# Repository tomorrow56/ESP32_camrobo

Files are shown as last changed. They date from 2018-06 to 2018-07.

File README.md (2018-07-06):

# ESP32_camrobo

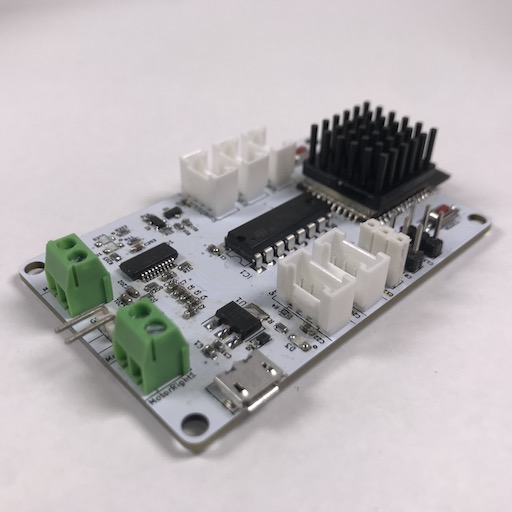
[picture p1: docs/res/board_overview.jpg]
ESP32Camrobo board


## Overview

[タミヤのカムプログラムロボット工作セット](http://www.tamiya.com/japan/products/70227/index.html) をマイコンロボット化するためのボート **ESP32Camrobo** と、それを使用した作例 **CrappyPark** についてのプロジェクトです。

## Get Started

### Arduinoでプログラミングするための準備

Arduinoでプログラムをボードに書き込むために以下の環境設定を行う。  

#### ESP32 ボードライブラリ

ESP32のBLE機能を使用するので、ESP32のボードライブラリを追加する。  

[arduino-esp32](https://github.com/espressif/arduino-esp32)  
**Installation Instructions** を参照してインストールする。  

参考) [Arduino IDEでESP32 BLEライブラリを導入](https://qiita.com/tomorrow56/items/afa06e206eec9fafcc7a)

#### ライブラリ

Arduino の **ライブラリマネージャ** から以下のライブラリをインストールする。  

- [Adafruit_NeoPixel](https://github.com/adafruit/Adafruit_NeoPixel)

## カムプログラムロボットの改造

ESP32Camroboをカムプログラムロボットに搭載し、改造する方法について解説しています。  

- [カムロボットの工作](./docs/make_robot/README.md)

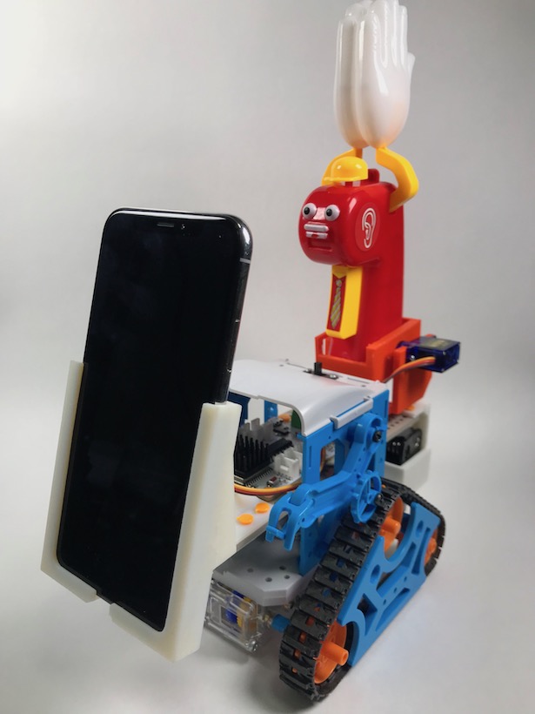
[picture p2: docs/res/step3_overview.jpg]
Camrobo Step3
  

*作成例(Step3)*

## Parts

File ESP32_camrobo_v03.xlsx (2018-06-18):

Reference | Value | Footprint | Note | Maker | URL
C1 | 10uF | Capacitors_SMD:C_0603
C2 | 10uF | Capacitors_SMD:C_0603
C3 | 10uF | Capacitors_SMD:C_0603
C4 | 10uF | Capacitors_SMD:C_0603
C5 | 10uF | Capacitors_SMD:C_0603
C6 | 10uF | Capacitors_SMD:C_0603
C7 | 10uF | Capacitors_SMD:C_0603
C8 | 10uF | Capacitors_SMD:C_0603
C9 | 10uF | Capacitors_SMD:C_0603
C10 | 0.1u | Capacitors_SMD:C_0603
C11 | 0.1u | Capacitors_SMD:C_0603
C12 | 10uF | Capacitors_SMD:C_0603
C13 | 10uF | Capacitors_SMD:C_0603
C14 | 10uF | Capacitors_SMD:C_0603
C15 | 10uF | Capacitors_SMD:C_0603
C16 | 10uF | Capacitors_SMD:C_0603
C17 | 10uF | Capacitors_SMD:C_0603
C20 | 10uF | Capacitors_SMD:C_0603
C22 | 10uF | Capacitors_SMD:C_0603
C200 | 10u | Capacitors_SMD:C_0603
C201 | 47p | Capacitors_SMD:C_0603
C202 | 47p | Capacitors_SMD:C_0603
C203 | 0.1u | Capacitors_SMD:C_0603
D1 | 1N4148 | Diodes_SMD:D_SOD-323
D2 | 1N4148 | Diodes_SMD:D_SOD-323
D3 | PowerLED | LEDs:LED_0805
D200 | RxLED | LEDs:LED_0805
D201 | TxLED | LEDs:LED_0805
Q1 | S8050 | TO_SOT_Packages_SMD:SOT-23
Q2 | S8050 | TO_SOT_Packages_SMD:SOT-23
R1 | 1k | Resistors_SMD:R_0603
R2 | 270 | Resistors_SMD:R_0603
R4 | 10k | Resistors_SMD:R_0603
R5 | 10k | Resistors_SMD:R_0603
R10 | 1k | Resistors_SMD:R_0603
R11 | 1k | Resistors_SMD:R_0603
R12 | 10k | Resistors_SMD:R_0603
R14 | 10k | Resistors_SMD:R_0603
R15 | 10k | Resistors_SMD:R_0603
R16 | 10k | Resistors_SMD:R_0603
R18 | 270 | Resistors_SMD:R_0603
R19 | DNP | footprint:SOLDERJUMPER_REFLOW
R21 | 270 | Resistors_SMD:R_0603
R200 | 27 | Resistors_SMD:R_0603
R201 | 27 | Resistors_SMD:R_0603
R202 | 1k | Resistors_SMD:R_0603
R203 | 1k | Resistors_SMD:R_0603
U1 | ADP3338AKCZ-3.3-RL | TO_SOT_Packages_SMD:SOT-223-3_TabPin2
U201 | FT231XS | SMD_Packages:SSOP-20
U301 | ESP-WROOM-32 | footprint:ESP-WROOM-32_aki
MicroUSB1 | USB_OTG | Connectors:USB_Micro-B
MODE1 | MODE | Buttons_Switches_SMD:SW_SPST_FSMSM
RESET1 | RESET | Buttons_Switches_SMD:SW_SPST_FSMSM
IC1 | L293D | Housings_DIP:DIP-16_W7.62mm_LongPads | IC MOTOR DRIVER PAR 16-DIP | STMicroelectronics
GroveANA1 | CONN_01X04 | footprint:Grove 2x2.00mm_Straight
GroveDIGI0 | CONN_01X04 | footprint:Grove 2x2.00mm_Straight
GroveDIGI1 | CONN_01X04 | footprint:Grove 2x2.00mm_Straight
GroveI2C1 | CONN_01X04 | footprint:Grove 2x2.00mm_Straight
GroveUART1 | CONN_01X04 | footprint:Grove 2x2.00mm_Straight
Neopixel1 | CONN_01X03 | Pin_Headers:Pin_Header_Straight_1x03_Pitch2.54mm
Servo1 | CONN_01X03 | Pin_Headers:Pin_Header_Straight_1x03_Pitch2.54mm
Servo2 | CONN_01X03 | Pin_Headers:Pin_Header_Straight_1x03_Pitch2.54mm
MotorPower1 | Terminal_01X02_FEMALE | Pin_Headers:Pin_Header_Angled_1x02_Pitch2.54mm
MotorLeft1 | Terminal_01X02_FEMALE | footprint:Terminal_2pin_Pitch3.5mm
MotorRight1 | Terminal_01X02_FEMALE | footprint:Terminal_2pin_Pitch3.5mm

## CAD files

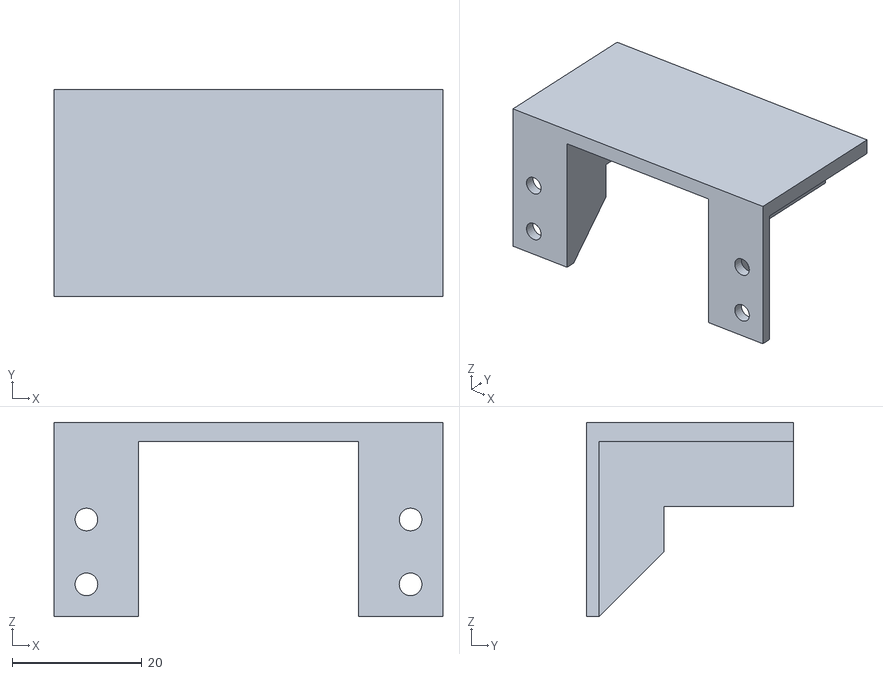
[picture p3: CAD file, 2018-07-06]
3d_parts/phone-base.stl
60.0 x 32.0 x 30.0

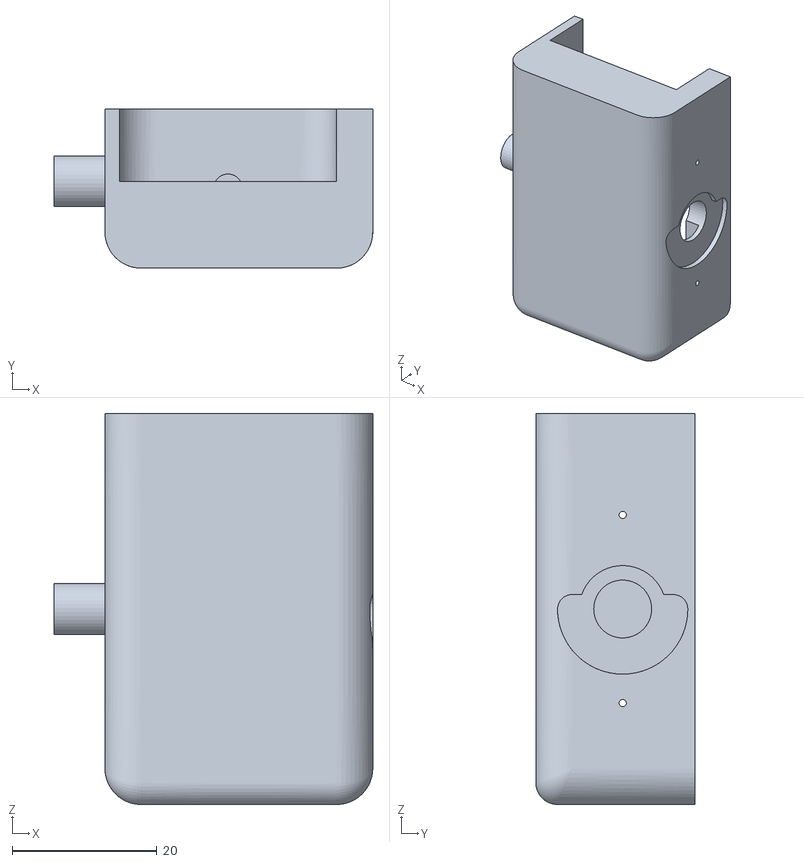
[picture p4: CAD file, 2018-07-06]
3d_parts/cp-mount-a.stl
44.0 x 22.0 x 54.0

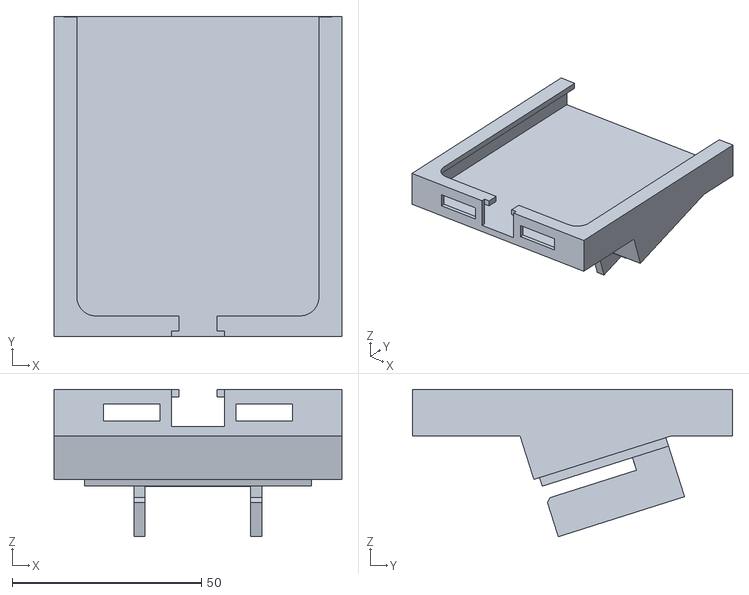
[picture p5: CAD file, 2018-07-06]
3d_parts/phone-mount-iphone-x-2017.stl
76.0 x 84.5 x 38.9

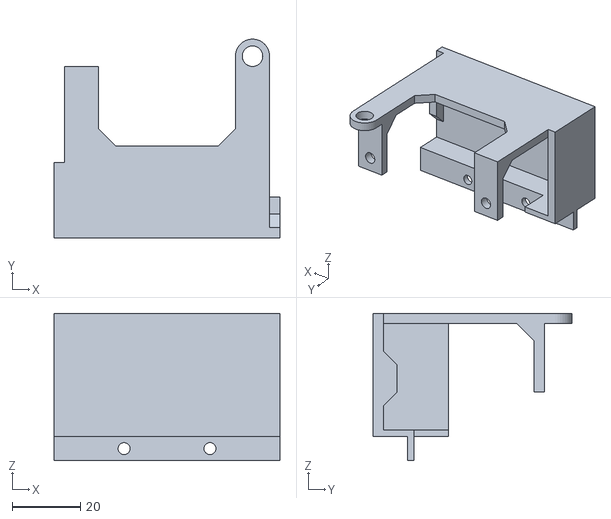
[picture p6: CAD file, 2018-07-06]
3d_parts/battery-holder.stl
66.0 x 58.1 x 43.0

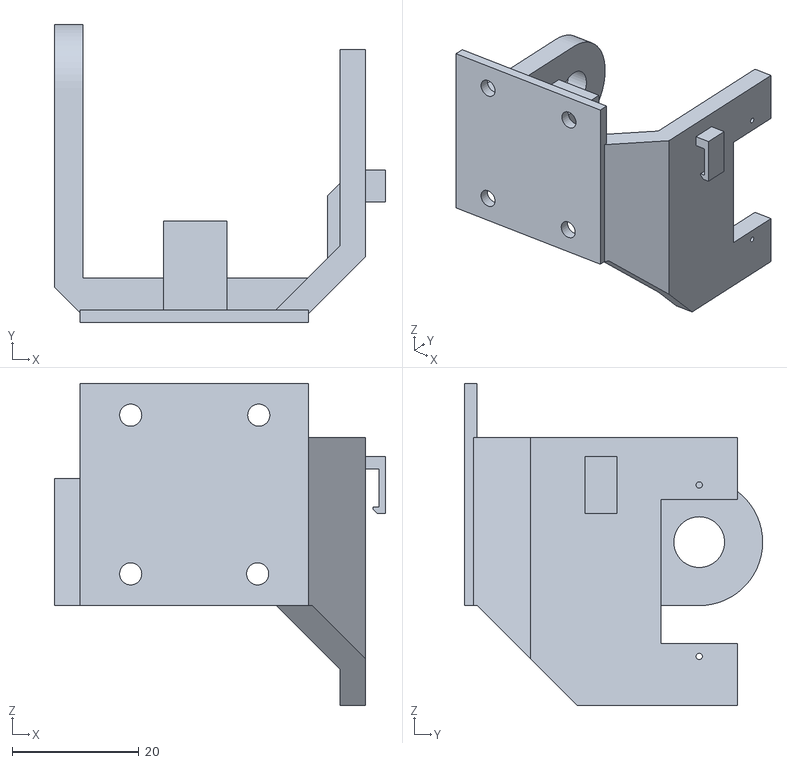
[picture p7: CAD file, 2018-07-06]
3d_parts/cp-mount-b.stl
52.1 x 47.0 x 50.8

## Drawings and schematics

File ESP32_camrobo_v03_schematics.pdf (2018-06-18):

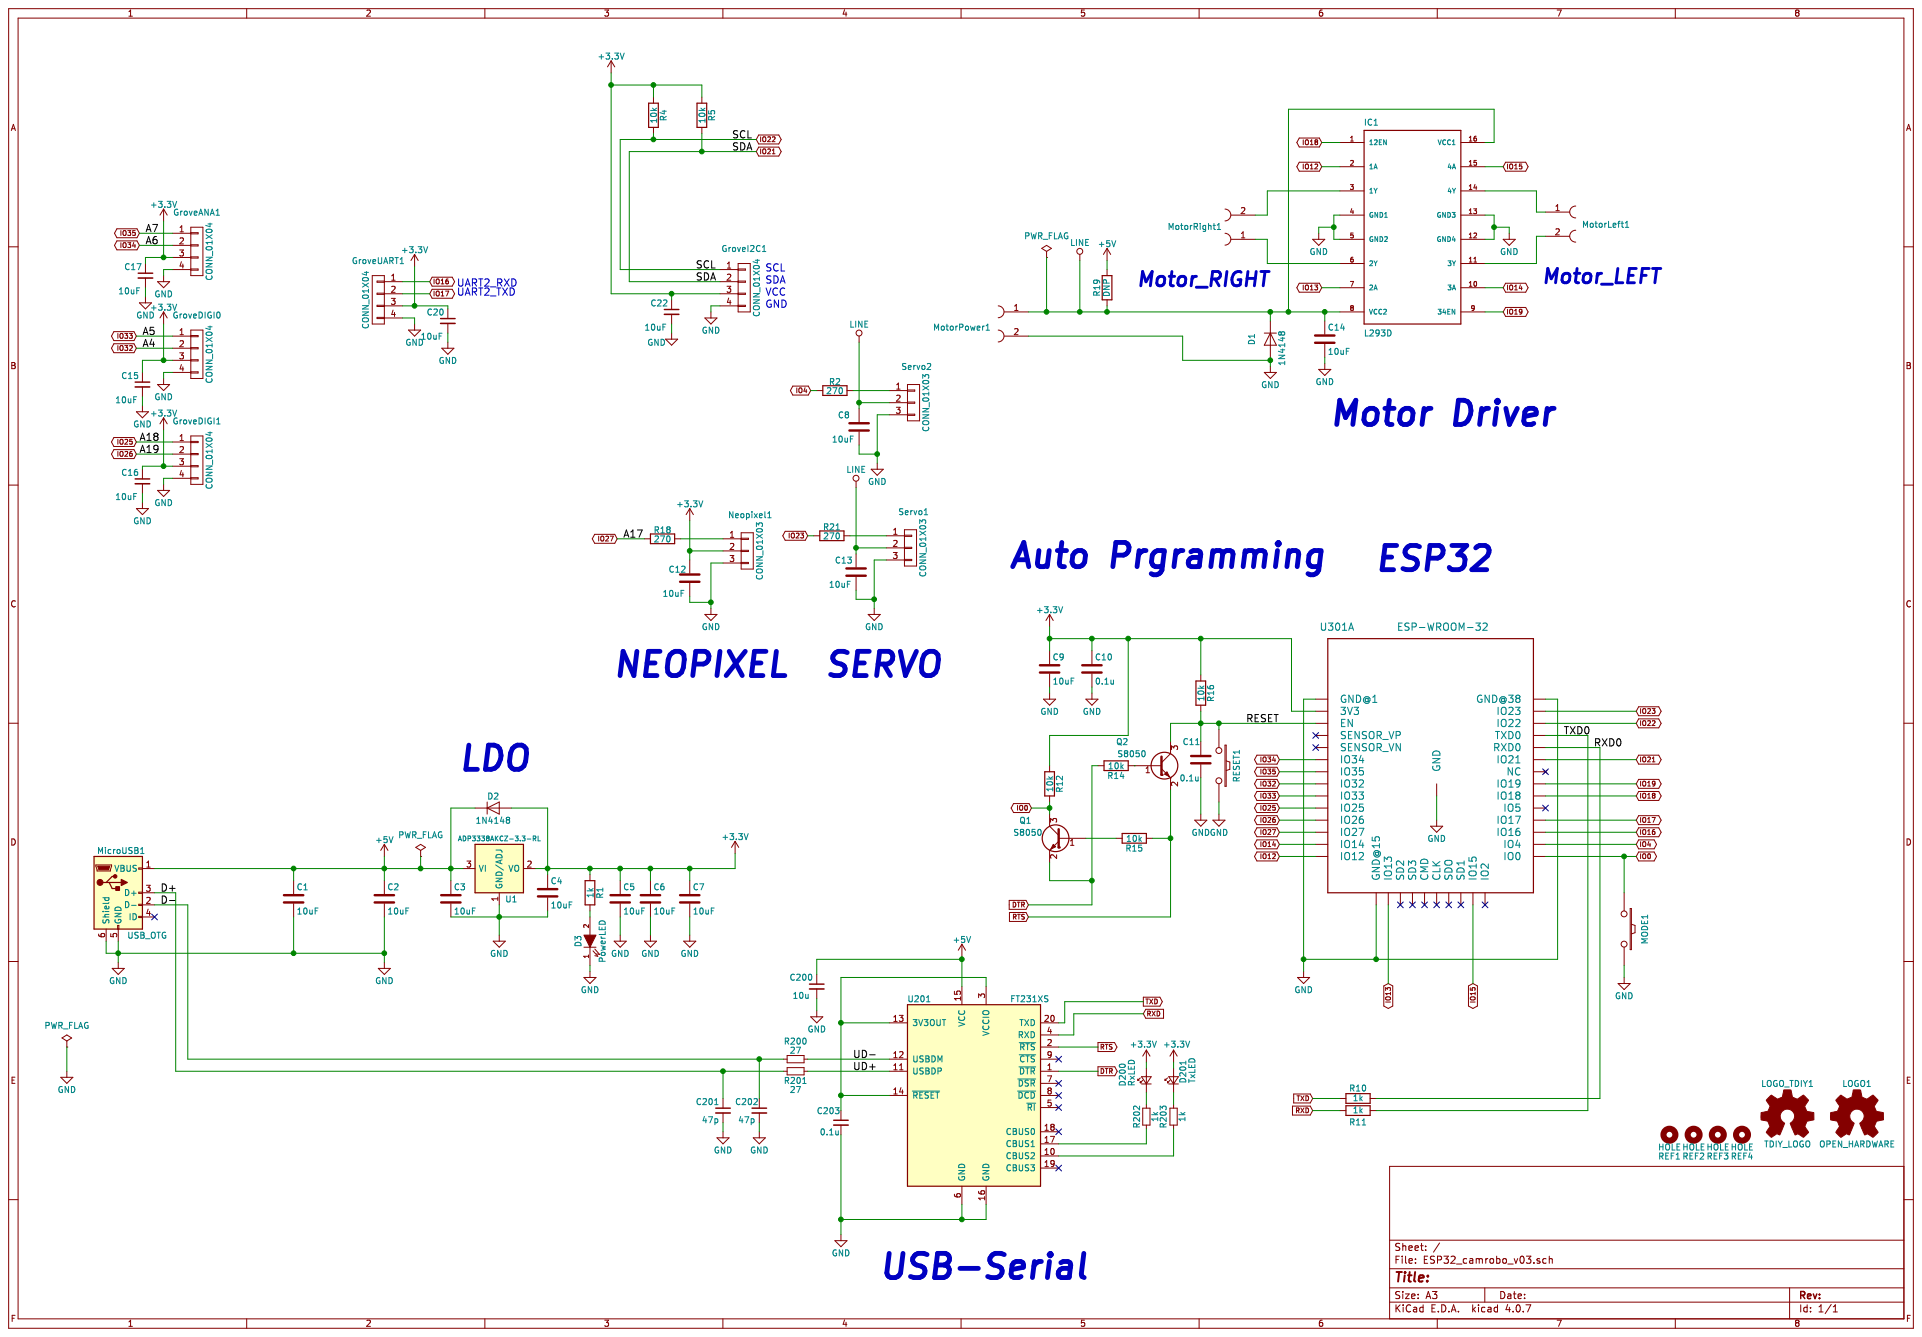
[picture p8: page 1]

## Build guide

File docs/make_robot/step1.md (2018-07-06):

# Step.1 リモコンロボット化

## Overview

ベースとなるカムプログラムロボットにESP32Camrobo基板を搭載して、スマートフォンからBLEで制御できるロボットに改造します。  
この工作は、他の全ての工作の元となります。  

## 部品の準備

- 以下の部品を購入します。
    - [カムプログラムロボット工作セット](http://www.tamiya.com/japan/products/70227/index.html)
    - ユニバーサルプレートとプッシュリベット(以下の組み合わせのうちどちらか)
        - [ユニバーサルプレート](http://www.tamiya.com/japan/products/70098/index.html) & [3mmプッシュリベットセット](http://www.tamiya.com/japan/products/70155/index.html)
        - [ユニバーサルプレート （2枚セット）](http://www.tamiya.com/japan/products/70157/index.html)
    - [電池ボックス　単３×４本　リード線・背中合わせ BH-343-3A](http://akizukidenshi.com/catalog/g/gP-02678/)
    - タッピング Aナベ 2x5mm ビス　2本
- 3Dプリンタでパーツを出力します。
    - [電池ボックスホルダー](../../3d_parts/battery-holder.stl)

## ESP32Camrobo基板の準備

電池ボックスの電池のみで動くようにするため、基板のR19を半田付けでブリッジしてショートさせます。

## 組立て

### 1. ユニバーサルプレートの固定

カムプログラムロボットを一旦組み立てます。  
カムプログラムロボットの説明書を参考に、ユニバーサルプレートを設置します。  

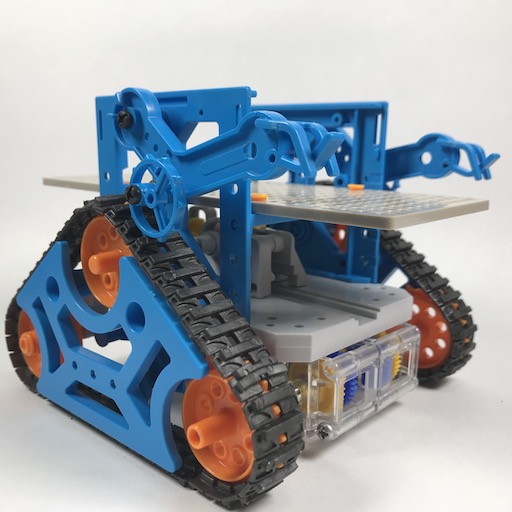
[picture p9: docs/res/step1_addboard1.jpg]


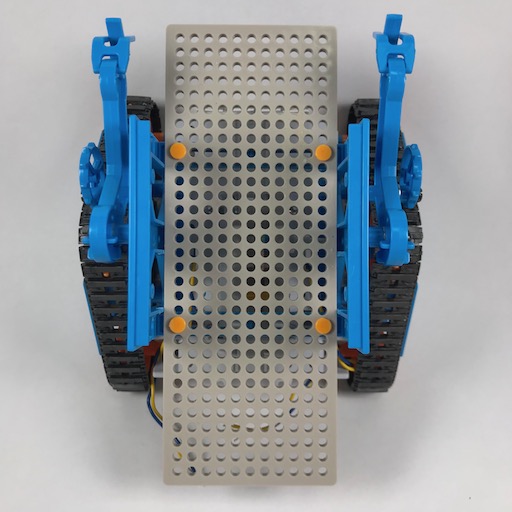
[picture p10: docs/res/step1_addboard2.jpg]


**固定位置に注意してください。写真を参考に、後方に10穴分余るようにしてください。**

### 2. ESP32Camrobo基板の設置

ユニバーサルプレートの中央にESP32Camrobo基板を固定します。  

- アンテナ側が前方に来るようにします。
- プッシュリベットを使用して固定します。

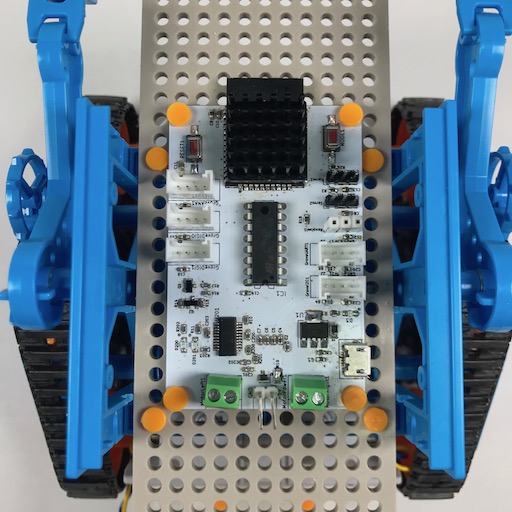
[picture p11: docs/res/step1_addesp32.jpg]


ESP32Camrobo基板にモーターを接続します。  

- カムプログラムロボットのモーターを `MotorLeft`, `MotorRight` ターミナルに接続します。
- カムプログラムロボットから見て左のモーターを `MotorLeft` に、右のモーターを `MotorRight` に、それぞれ接続します。

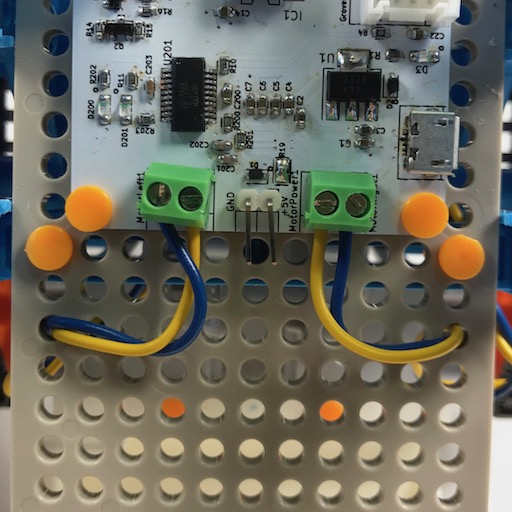
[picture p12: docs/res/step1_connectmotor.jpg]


### 3. 電池ボックスの設置

電池ボックスホルダーをカムプログラムロボットに固定します。  
本体の土台部分に2箇所、ユニバーサルプレートの後方に2箇所、それぞれプッシュリベットを使用して固定します。  

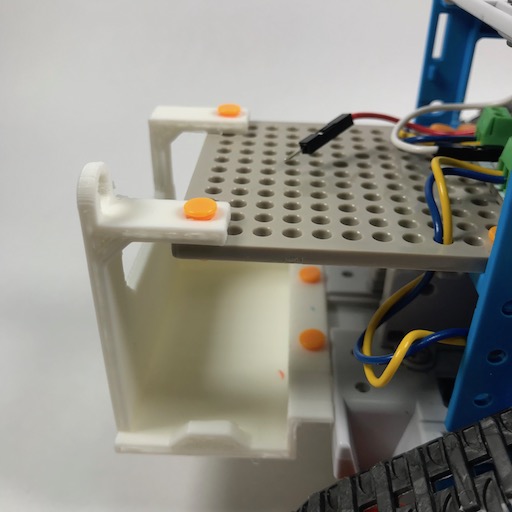
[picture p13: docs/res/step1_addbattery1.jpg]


電池ボックスを `+5V`, `GND` ピンに接続します。  

- 適宜、QIコネクタ等を使用してください。
- 間に、カムプログラムロボットに付属のスイッチを挟むと操作がしやすくなります。

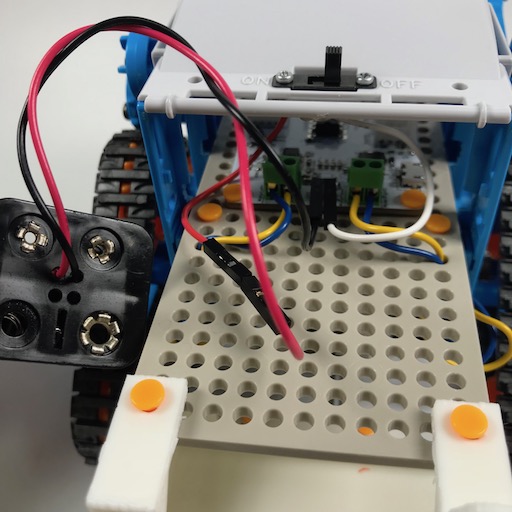
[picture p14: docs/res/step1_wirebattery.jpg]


電池ボックスを電池ボックスホルダーに格納します。  
幅が広い方向を縦にしてください。  

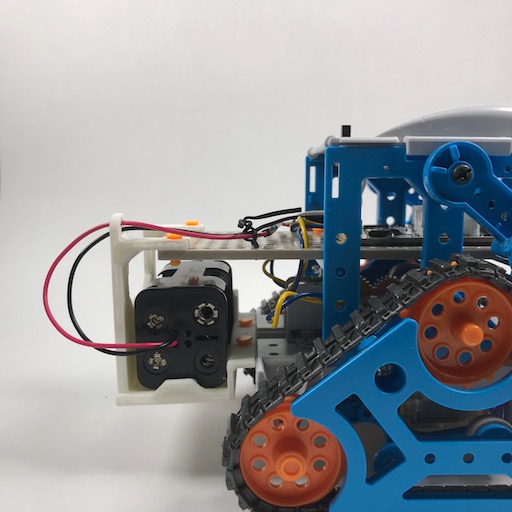
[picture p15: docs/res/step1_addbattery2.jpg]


## プログラムの書き込み

ESP32Camrobo基板にArduinoでプログラムを書き込みます。  

[ESP32_ClappyPark](../../ESP32_ClappyPark_v03)  

## 動作確認

リモコンのアプリを端末(スマートフォン or PC)のブラウザ開き、接続と操作を試します。  

- https://crappypark.uzukiaoba.net/

### リモコンアプリが使用可能な端末について

[Web Bluetooth](https://webbluetoothcg.github.io/web-bluetooth/)が使用可能な端末で利用できます。

- Chromeがインストールされた Android ５.0以上のAndroid端末
- Chromeがインストールされた Macbook, Macbook Pro
- Chromeがインストールされ、なおかつBLEをサポートする Windows PC

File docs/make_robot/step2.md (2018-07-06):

# Step.2 クラッピーを搭載

## Overview

TBD

## 部品の準備

- 以下の部品を購入します。
    - [Tower Pro Micro Servo SG90](http://akizukidenshi.com/catalog/g/gM-08761/)
- 3Dプリンタでパーツを出力します。
    - [クラッピーマウンターA](../../3d_parts/cp-mount-a.stl)
    - [クラッピーマウンターB](../../3d_parts/cp-mount-b.stl)

## 組立て

TBD

## プログラムの書き込み

TBD

## 動作確認

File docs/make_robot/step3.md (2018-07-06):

# Step.3 AIロボット化

## Overview

TBD

## 部品の準備

- 以下の部品を購入します。
    - Apple iPhone X
- 3Dプリンタでパーツを出力します。
    - [スマホマウンターベース](../../3d_parts/phone-base.stl)
    - [スマホマウンター(iPhone X用)](../../3d_parts/phone-mount-iphone-x-2017.stl)

## 組立て

TBD

## プログラムの書き込み

TBD

## 動作確認

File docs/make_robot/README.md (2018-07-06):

# カムロボットの工作

## Overview

ESP32Camrobo基盤を使用して、カムプログラムロボットを改造する手順について記述します。  

## 使用する部品について

- タミヤの **楽しい工作シリーズ** の部品を使用します。量販店等でご購入ください。
- 一部、電子部品を使用します。電子部品専門店か、秋月電子等の通販でご購入ください。
- 本工作専用の部品について、3D CADで作成したパーツがありますので、適宜3Dプリンタで出力して使用してください。
    - [パーツのSTLファイルはこちら](../../3d_parts)

## Step.1 リモコンロボット化

カムプログラムロボットにESP32Camroboを組み込み、スマホから操作可能なリモコンロボットに改造します。  

[Step.1 の工作の内容はこちら](./step1.md)

## Step.2 クラッピーを搭載

Step.1 をベースに、サーボで動くクラッピーを追加します。  

[Step.2 の工作の内容はこちら](./step2.md)

## Step.3 AIロボット化

Step.2 をベースに、AI制御の自律動作ロボットを作ります。  

[Step.3 の工作の内容はこちら](./step3.md)

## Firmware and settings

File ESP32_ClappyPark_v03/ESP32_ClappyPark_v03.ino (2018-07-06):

#include <BLEDevice.h>
#include <BLEServer.h>
#include <BLEUtils.h>
#include <BLE2902.h>

#include "ClappyPark_v03.h"

#include <Wire.h>
//#include "SSD1306.h" // alias for `#include "SSD1306Wire.h"`

#include <Adafruit_NeoPixel.h>
#define NEO_NUM 12

//SSD1306  display(0x3c, I2CSDA, I2CSCL);

Adafruit_NeoPixel pixels = Adafruit_NeoPixel(NEO_NUM, NEO_PIN, NEO_GRB + NEO_KHZ800);

//Use LCDC for Servo Control
// use first channel of 16 channels (started from zero)
#define LEDC_CHANNEL_0     0
// use 10 bit precission for LEDC timer
#define LEDC_TIMER_BIT  10
// use 50 Hz as a LEDC base frequency
#define LEDC_BASE_FREQ     50

// int min = 26;  // (26/1024)*20ms ≒ 0.5 ms  (-90°)
int min = 75;  // (26/1024)*20ms ≒ 0.5 ms  (-90°)
int max = 123; // (123/1024)*20ms ≒ 2.4 ms (+90°)
int n = min;
boolean srv_flg = false;

void setup_tb6612() {
  pinMode( TB_A1, OUTPUT );
  pinMode( TB_A2, OUTPUT );
  pinMode( TB_Ap, OUTPUT );
  pinMode( TB_B1, OUTPUT );
  pinMode( TB_B2, OUTPUT );
  pinMode( TB_Bp, OUTPUT );
   
  digitalWrite( TB_A1, LOW );
  digitalWrite( TB_A2, LOW );
  digitalWrite( TB_Ap, LOW );
  digitalWrite( TB_B1, LOW );
  digitalWrite( TB_B2, LOW );
  digitalWrite( TB_Bp, LOW );
}

void cmd_motorA_forward() {
  Serial.println("motorA forward");
  digitalWrite( TB_Ap, HIGH );
  digitalWrite( TB_A1, HIGH );
  digitalWrite( TB_A2, LOW );
}
void cmd_motorA_back() {
  Serial.println("motorA back");
  digitalWrite( TB_Ap, HIGH );
  digitalWrite( TB_A1, LOW );
  digitalWrite( TB_A2, HIGH );
}
void cmd_motorA_stop() {
  Serial.println("motorA stop");
  digitalWrite( TB_Ap, LOW );
}

void cmd_motorB_forward() {
  Serial.println("motorB forward");
  digitalWrite( TB_Bp, HIGH );
  digitalWrite( TB_B1, HIGH );
  digitalWrite( TB_B2, LOW );
}
void cmd_motorB_back() {
  Serial.println("motorB back");
  digitalWrite( TB_Bp, HIGH );
  digitalWrite( TB_B1, LOW );
  digitalWrite( TB_B2, HIGH );
}
void cmd_motorB_stop() {
  Serial.println("motorB stop");
  digitalWrite( TB_Bp, LOW );
}

void cmd_forward() {
  Serial.println("all forward");
  
  digitalWrite( TB_Ap, HIGH );
  digitalWrite( TB_A1, HIGH );
  digitalWrite( TB_A2, LOW );
  
  digitalWrite( TB_Bp, HIGH );
  digitalWrite( TB_B1, HIGH );
  digitalWrite( TB_B2, LOW );
}

void cmd_back() {
  Serial.println("all back");
  
  digitalWrite( TB_Ap, HIGH );
  digitalWrite( TB_A1, LOW );
  digitalWrite( TB_A2, HIGH );
  
  digitalWrite( TB_Bp, HIGH );
  digitalWrite( TB_B1, LOW );
  digitalWrite( TB_B2, HIGH );
}

void cmd_stop() {
  Serial.println("all stop");
  
  digitalWrite( TB_Ap, LOW );

  digitalWrite( TB_Bp, LOW );
}

void cmd_spin_turn() {
  Serial.println("spin turn");
  
  digitalWrite( TB_Ap, HIGH );
  digitalWrite( TB_A1, HIGH );
  digitalWrite( TB_A2, LOW );
  
  digitalWrite( TB_Bp, HIGH );
  digitalWrite( TB_B1, LOW );
  digitalWrite( TB_B2, HIGH );
}

void cmd_turn_left() {
  Serial.println("turn left");
  
  digitalWrite( TB_Ap, LOW );
  digitalWrite( TB_A1, HIGH );
  digitalWrite( TB_A2, LOW );
  
  digitalWrite( TB_Bp, HIGH );
  digitalWrite( TB_B1, HIGH );
  digitalWrite( TB_B2, LOW );
}

void cmd_turn_right() {
  Serial.println("turn right");
  
  digitalWrite( TB_Ap, HIGH );
  digitalWrite( TB_A1, HIGH );
  digitalWrite( TB_A2, LOW );
  
  digitalWrite( TB_Bp, LOW );
  digitalWrite( TB_B1, HIGH );
  digitalWrite( TB_B2, LOW );
}

void cmd_srv_on() {
  if(srv_flg == false){
    srv_flg = true;
    for(n = min; n <= max; n++){
      ledcWrite(0, n);
      delay(10);
    }
  }
}

void cmd_srv_off() {
  if(srv_flg == true){
    srv_flg = false;
    for(n = max; n >= min; n--){
      ledcWrite(0, n);
      delay(10);
    }
  }
}

//------------------------------------------
// BLE
//------------------------------------------

#define DEVICE_NAME  "CLAPPY_PARK"
#define SERVICE_UUID         "6E400001-B5A3-F393-E0A9-E50E24DCCA9E"
#define CHARACTERISTIC_UUID  "6E400002-B5A3-F393-E0A9-E50E24DCCA9E"
#define CHARACTERISTIC2_UUID  "6E400003-B5A3-F393-E0A9-E50E24DCCA9E"

/**************
value kind            need time param?  description
0x01  CMD_FORWARD     YES 指定した時間前進
0x02  CMD_BACK        YES 指定した時間後進
0xFF  CMD_STOP        NO  停止
0x11  CMD_SPIN_TURN   NO  超信地旋回で180度回転
0x12  CMD_TURN_LEFT   YES 指定した時間左回転
0x13  CMD_TURN_RIGHT  YES 指定した時間右回転
0x21  CMD_SRV_ON      NO  クラッピーを起こす
0x22  CMD_SRV_OFF     NO  クラッピーを倒す　
*/

#define CMD_FORWARD    0x01
#define CMD_BACK       0x02
#define CMD_STOP       0xFF
#define CMD_SPIN_TURN  0x11
#define CMD_TURN_LEFT  0x12
#define CMD_TURN_RIGHT 0x13

#define CMD_SRV_ON     0x21
#define CMD_SRV_OFF    0x22

#define TURN_TIME 0x0E74

uint8_t CMD_CURRENT = 0x00;

uint16_t EXEC_TIME = 0;

unsigned long start_time;

//Characteristic
BLECharacteristic *pCharacteristic;
BLECharacteristic *pCharacteristic2;

class MyCallbacks: public BLECharacteristicCallbacks {
    void onWrite(BLECharacteristic *pChara) {
      std::string value = pChara->getValue();
//      int value = pChara->getValue(); //cannot convert 'std::__cxx11::string {aka std::__cxx11::basic_string<char>}' to 'int' in initialization

      if (value.length() > 0) {
        if ((int)value[0] == CMD_FORWARD){
          if(CMD_CURRENT != CMD_FORWARD){
            CMD_CURRENT = CMD_FORWARD;
            cmd_forward();
            start_time = millis();
            EXEC_TIME = ((int)value[2] << 8) + (int)value[1];
            for(int i=0;i<NEO_NUM;i++){
              pixels.setPixelColor(i, pixels.Color(150,0,0)); // Moderately bright green color.
              delay(10);
              pixels.show(); // This sends the updated pixel color to the hardware.
            }
          }
        } else if ((int)value[0] == CMD_BACK){
          if(CMD_CURRENT != CMD_BACK){
            CMD_CURRENT = CMD_BACK;
            cmd_back();
            start_time = millis();
            EXEC_TIME = ((int)value[2] << 8) + (int)value[1];
            for(int i=0;i<NEO_NUM;i++){
              pixels.setPixelColor(i, pixels.Color(0,0,150)); // Moderately bright green color.
              delay(10);
              pixels.show(); // This sends the updated pixel color to the hardware.
            }
          }
        } else if ((int)value[0] == CMD_STOP){
          if(CMD_CURRENT != CMD_STOP){
            CMD_CURRENT = CMD_STOP;
            cmd_stop();
            EXEC_TIME = 0;
            for(int i=0;i<NEO_NUM;i++){
              pixels.setPixelColor(i, pixels.Color(0,150,0)); // Moderately bright green color.
              delay(10);
              pixels.show(); // This sends the updated pixel color to the hardware.
            }
          }
        } else if ((int)value[0] == CMD_SPIN_TURN){
          if(CMD_CURRENT != CMD_SPIN_TURN){
            CMD_CURRENT = CMD_SPIN_TURN;
            cmd_spin_turn();
            start_time = millis();
//            EXEC_TIME = ((int)value[2] << 8) + (int)value[1];
              EXEC_TIME = TURN_TIME;
            for(int i=0;i<NEO_NUM;i++){
              pixels.setPixelColor(i, pixels.Color(150,0,0)); // Moderately bright green color.
              delay(10);
              pixels.show(); // This sends the updated pixel color to the hardware.
            }
          }
        } else if ((int)value[0] == CMD_TURN_LEFT){
          if(CMD_CURRENT != CMD_TURN_LEFT){
            CMD_CURRENT = CMD_TURN_LEFT;
            cmd_turn_left();
            start_time = millis();
            EXEC_TIME = ((int)value[2] << 8) + (int)value[1];
            for(int i=0;i<NEO_NUM;i++){
              pixels.setPixelColor(i, pixels.Color(150,0,0)); // Moderately bright green color.
              delay(10);
              pixels.show(); // This sends the updated pixel color to the hardware.
            }
          }
        } else if ((int)value[0] == CMD_TURN_RIGHT){
          if(CMD_CURRENT != CMD_TURN_RIGHT){
            CMD_CURRENT = CMD_TURN_RIGHT;
            cmd_turn_right();
            start_time = millis();
            EXEC_TIME = ((int)value[2] << 8) + (int)value[1];
            for(int i=0;i<NEO_NUM;i++){
              pixels.setPixelColor(i, pixels.Color(150,0,0)); // Moderately bright green color.
              delay(10);
              pixels.show(); // This sends the updated pixel color to the hardware.
            }
          }
        } else if ((int)value[0] == CMD_SRV_ON){
          cmd_srv_on();
          for(int i=0;i<NEO_NUM;i++){
            pixels.setPixelColor(i, pixels.Color(0,150,0)); // Moderately bright green color.
            delay(10);
            pixels.show(); // This sends the updated pixel color to the hardware.
          }
        } else if ((int)value[0] == CMD_SRV_OFF){
          cmd_srv_off();
          for(int i=0;i<NEO_NUM;i++){
            pixels.setPixelColor(i, pixels.Color(0,0,0)); // Moderately bright green color.
            delay(10);
            pixels.show(); // This sends the updated pixel color to the hardware.
          }

        } else {
          Serial.println("*********");
          Serial.print("New value: ");
          for (int i=0; i<value.length(); i++){
            Serial.print((int)value[i]);
          }
          Serial.println();
          Serial.println("*********");
        }
          Serial.println(EXEC_TIME);

      }
    }
};

void setup_ble() {
    // BLEデバイス名の定義
    BLEDevice::init(DEVICE_NAME);
    // BLEサーバーの定義
    BLEServer *pServer = BLEDevice::createServer();
    // BLEサービスの定義
    BLEService *pService = pServer->createService(SERVICE_UUID);
    // Characteristicの定義
    pCharacteristic = pService->createCharacteristic(
                        CHARACTERISTIC_UUID,
                        BLECharacteristic::PROPERTY_READ | BLECharacteristic::PROPERTY_WRITE
                        );
    pCharacteristic->addDescriptor(new BLE2902());
    pCharacteristic->setCallbacks(new MyCallbacks());
    pCharacteristic->setValue("off");
    
    pCharacteristic2 = pService->createCharacteristic(
                        CHARACTERISTIC2_UUID,
                        BLECharacteristic::PROPERTY_READ | BLECharacteristic::PROPERTY_NOTIFY
                        );
    pCharacteristic2->addDescriptor(new BLE2902());
    pCharacteristic2->setValue("dmcd");

    // Start
    pService->start();

    // Start advertising
    pServer->getAdvertising()->start();
    Serial.println("Waiting a client connection to notify...");
}

// Timer Interrupt setting
hw_timer_t * timer = NULL;

volatile SemaphoreHandle_t timerSemaphore;
portMUX_TYPE timerMux = portMUX_INITIALIZER_UNLOCKED;

void IRAM_ATTR onTimer(){
  // Increment the counter and set the time of ISR
  portENTER_CRITICAL_ISR(&timerMux);

  /*** ここにタイマー割り込みで実行するコードを記載 ***/
  if( EXEC_TIME > 0){
    if(millis() > start_time + EXEC_TIME){
       CMD_CURRENT = CMD_STOP;
       cmd_stop();
      for(int i=0;i<NEO_NUM;i++){
        pixels.setPixelColor(i, pixels.Color(0,150,0)); // Moderately bright green color.
        delay(10);
        pixels.show(); // This sends the updated pixel color to the hardware.
      }
       EXEC_TIME = 0;
    }
  }

  portEXIT_CRITICAL_ISR(&timerMux);
  // Give a semaphore that we can check in the loop
  xSemaphoreGiveFromISR(timerSemaphore, NULL);
  // It is safe to use digitalRead/Write here if you want to toggle an output
}

//------------------------------------------
// Main logics
//------------------------------------------

void setup() { 
    Serial.begin(115200);

    setup_tb6612();
    cmd_stop();
    
    setup_ble();

    // Setup timer and attach timer to a led pin
    ledcSetup(LEDC_CHANNEL_0, LEDC_BASE_FREQ, LEDC_TIMER_BIT);
    ledcAttachPin(Servo_PIN1, LEDC_CHANNEL_0);

    ledcWrite(0, n);

    // Create semaphore to inform us   when the timer has fired
    timerSemaphore = xSemaphoreCreateBinary();
    // Use 1st timer of 4 (counted from zero).
    // Set 80 divider for prescaler (see ESP32 Technical Reference Manual for more info).
    timer = timerBegin(0, 80, true);
    // Attach onTimer function to our timer.
    timerAttachInterrupt(timer, &onTimer, true);
    // Set alarm to call onTimer function every second (value in microseconds).
    // Repeat the alarm (third parameter)
    timerAlarmWrite(timer, 1000, true);
    // Start an alarm
    timerAlarmEnable(timer);

    pixels.begin(); // This initializes the NeoPixel library.
    for(int i=0;i<NEO_NUM;i++){
      pixels.setPixelColor(i, pixels.Color(0,0,0)); // Moderately bright green color.
      delay(1);
      pixels.show(); // This sends the updated pixel color to the hardware.
    }

//  // Initialising the UI will init the display too.
//  display.init();
//
//  display.flipScreenVertically();
//  
//  display.setFont(ArialMT_Plain_16);
//  display.drawString(20, 20, "Clappy Park");
//
//  display.setFont(ArialMT_Plain_10);
//  display.drawString(60, 50, "Setup done");
//  display.display();

  Serial.println( "Setup done");
  Serial.println( "*** Welcome to Clappy Park! ***");
  Serial.println( "CMD_FORWARD    0x01 + time"); 
  Serial.println( "CMD_BACK       0x02 + time");
  Serial.println( "CMD_STOP       0xFF");
  Serial.println( "CMD_SPIN_TURN  0x11");
  Serial.println( "CMD_TURN_LEFT  0x12 + time");
  Serial.println( "CMD_TURN_RIGHT 0x13 + time");
  Serial.println( "CMD_SRV_ON     0x21");
  Serial.println( "CMD_SRV_OFF    0x22");
}

void loop() {
//  Serial.println(n);
//  ledcWrite(0, n);
//  n+=5;
//  if (n > max) n = min;
//  delay(500);
}

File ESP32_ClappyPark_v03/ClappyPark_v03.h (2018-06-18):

#ifndef ClappyPark_v03_h_
#define ClappyPark_v03_h_

//------------------------------------------
// Moter Driver
//------------------------------------------
#define TB_A1   12  // moterA IN1
#define TB_A2   13  // moterA IN2
#define TB_Ap   18  // moterA PWM
#define TB_B1   14  // moterB IN1
#define TB_B2   15  // moterB IN2
#define TB_Bp   19  // moterB PWM

#define NEO_PIN     27
#define Servo_PIN1  23
#define Servo_PIN2  4

#define ANA01   35
#define ANA02   34

#define DIGI01  33
#define DIGI02  32
#define DIGI11  25
#define DIGI12  26

#define I2CSDA  21
#define I2CSCL  22

// UART2
#define UART2RXD 16
#define UART2TXD 17

#endif

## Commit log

2018-06-18 Add Schematics
    [ESP32_camrobo_v03.xlsx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]
2018-07-05 OLED Display was omitted on latest board.
2018-07-06 isolate document by section. add stl models.
    [battery-holder.stl, cp-mount-a.stl, cp-mount-b.stl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]
